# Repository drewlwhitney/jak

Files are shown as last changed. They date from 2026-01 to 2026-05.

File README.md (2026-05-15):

# Just Another Keyboard
It's Just Another Keyboard that amalgamates the [Corne](github.com/foostan/crkbd), [Ferris Sweep](https://github.com/davidphilipbarr/Sweep), and [Fifi](https://github.com/raychengy/fifi_split_keeb).

Wired | Wireless
-|-
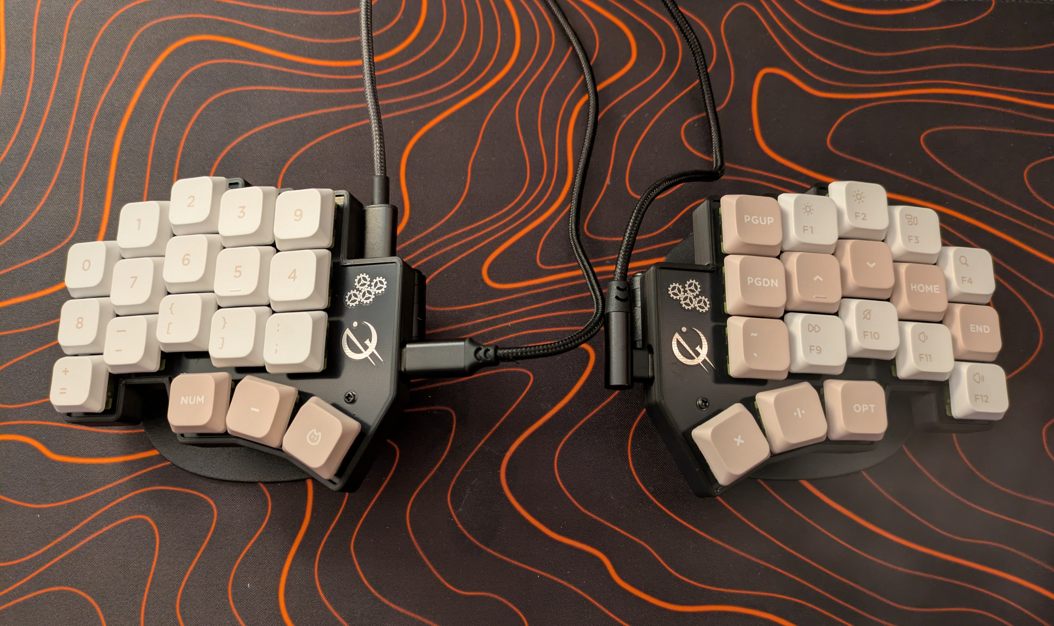
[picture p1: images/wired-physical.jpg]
wired_physical
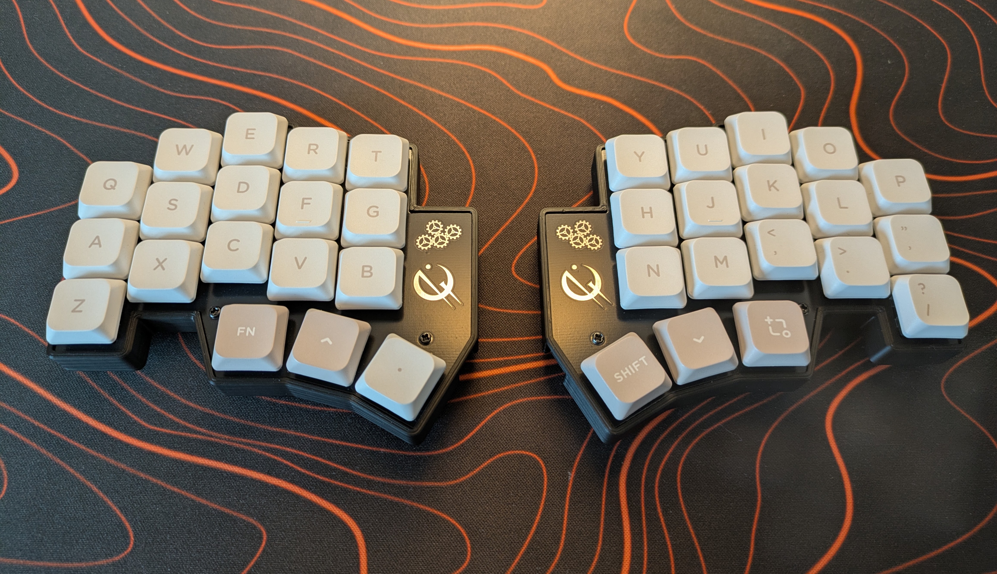
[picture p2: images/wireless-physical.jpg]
wireless_physical
 | 
<sub>Fully assembled wired version with keycaps from Nuphy</sub> | <sub>Fully assembled wireless version

## Notable Features
- Designed for [Gateron KS-33 Low Profile Switches](https://www.gateron.co/products/gateron-low-profile-mechanical-switch-set) with hotswap sockets

- Uses the [Seeed Studio XIAO microcontroller](https://www.seeedstudio.com/XIAO-RP2040-v1-0-p-5026.html) with either the [RP2040](https://www.seeedstudio.com/XIAO-RP2040-v1-0-p-5026.html) variant (for wired builds) or the [XIAO-BLE](https://www.seeedstudio.com/Seeed-XIAO-BLE-nRF52840-p-5201.html) variant (for wireless builds)

- 2-pin JST connector for the battery in wireless builds

- USB-C full duplex USART communication for wired builds. None of that [TRRS nonesense](https://gabevenberg.com/posts/stop-using-trrs/)!

- [Switch plates](./switch-plate/) you can order with the PCB

- [3D printable cases](./case/) that exactly fit the boards with a battery or USB-C connectors

## Build Guide
Refer to the [Build Guide](./docs/build_guide.md).

## Firmware Guide
### ZMK
You can use ZMK with *either* the wired or wireless version of the keyboard.

- Follow the [usual setup steps for ZMK](https://zmk.dev/docs/user-setup).

- Add the `zmk-keyboards-jak` module by following the instructions on the [module's GitHub](https://github.com/drewlwhitney/zmk-keyboards-jak).

- For wired builds, follow the extra steps on the [module's GitHub](https://github.com/drewlwhitney/zmk-keyboards-jak).

- Build and flash the firmware.

### QMK
You can use QMK with the **wired version only**.

- Follow the [usual setup steps for QMK](https://docs.qmk.fm/newbs).

- Clone the [keyboard description repo](https://github.com/drewlwhitney/qmk-keyboards-jak) into your `qmk_firmware/keyboards` folder and rename it to `"jak"`.[^1]

- Follow the build instructions from the [keyboard description repo](https://github.com/drewlwhitney/qmk-keyboards-jak).

[^1]: If there is a better way to do this, please open an issue to let me know!

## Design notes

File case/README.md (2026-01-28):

# Case
Left and right case files which can be 3D printed. There are two versions: one for a wired build and one for a wireless build.

## Wireless
Use the [wireless left](./left-wireless.step) and [wireless right](./right-wireless.step) files. This version omits holes for the split USB-C connectors and adds holes for the power switches. It is tall enough to fit a battery on the underside of the PCB.

This case uses 10mm M2 screws.

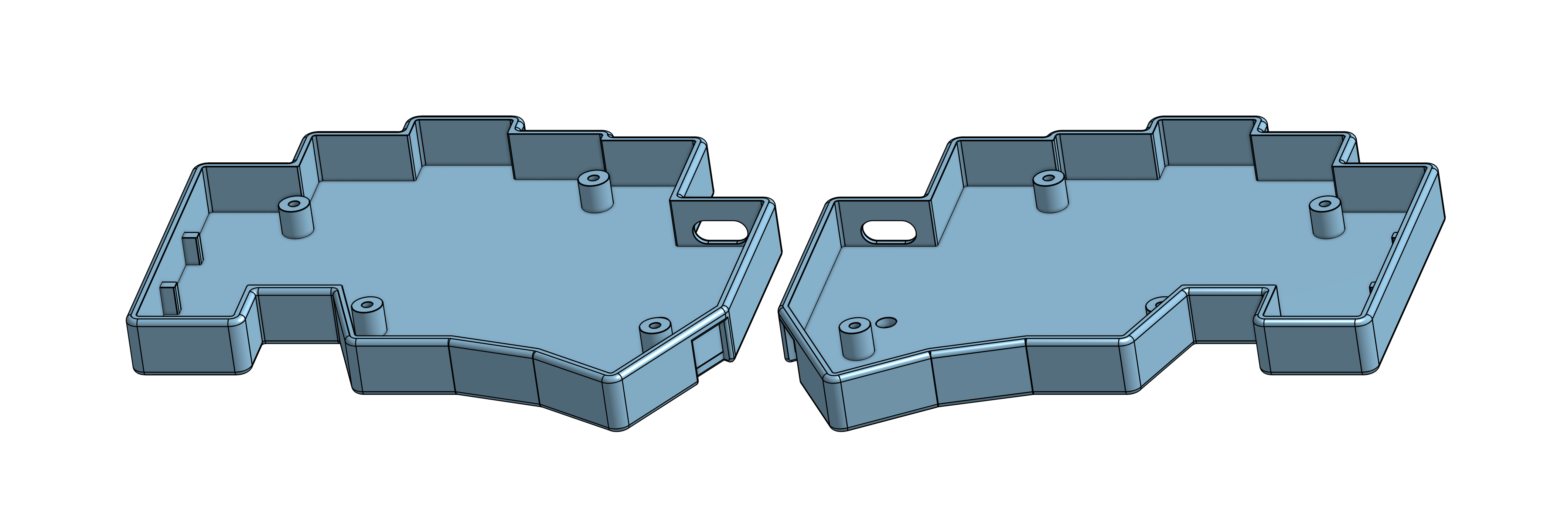
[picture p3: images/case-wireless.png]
case_wireless_onshape


## Wired
Use the [wired left](./left-wired.step) and [wired right](./right-wired.step) files. This version omits holes for the power switch and adds holes for the split USB-C connectors. It is tall enough to exactly fit the switch plate and PCB (with components) with nothing underneath.

This case uses 8mm M2 screws.

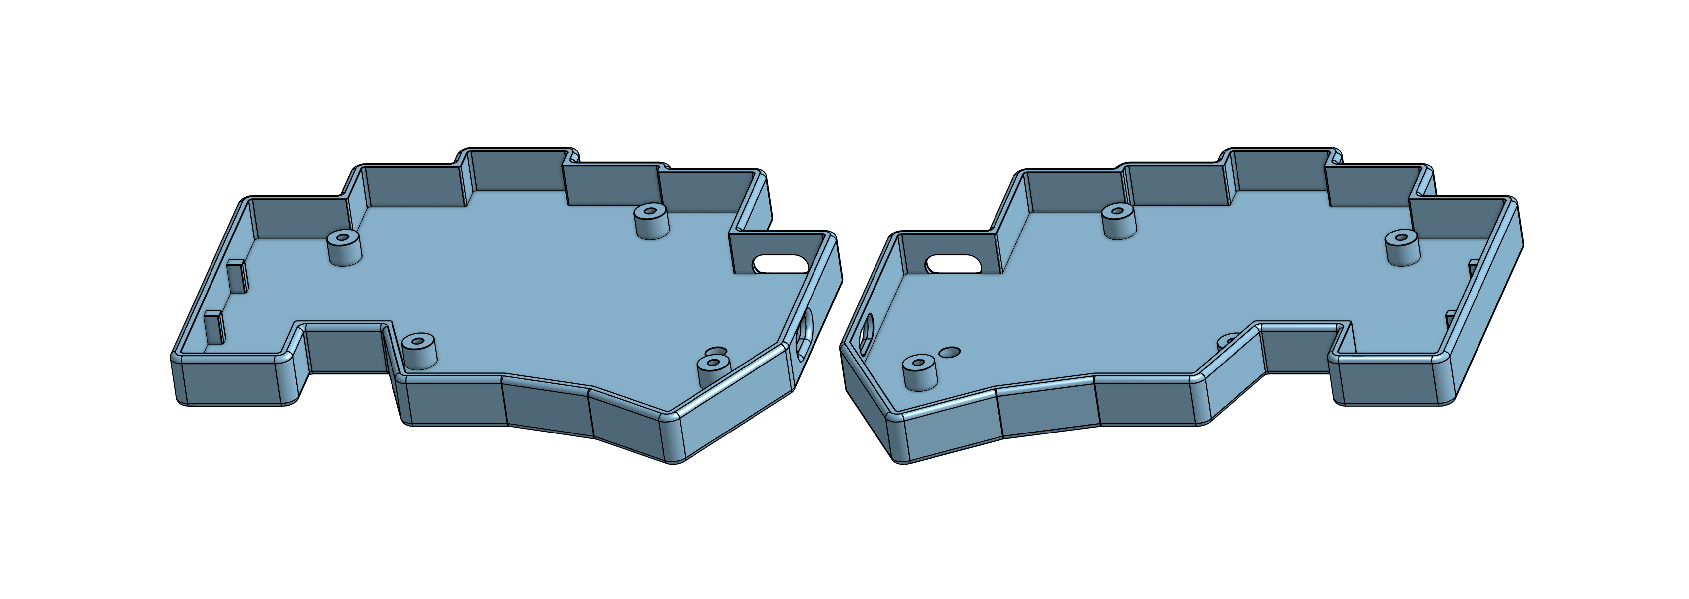
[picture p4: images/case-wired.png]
case_wired_onshape


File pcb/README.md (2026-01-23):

## PCB
The PCB is non-reversible and is designed for Gateron KS-33 Low Profile Switches with hotswap sockets.

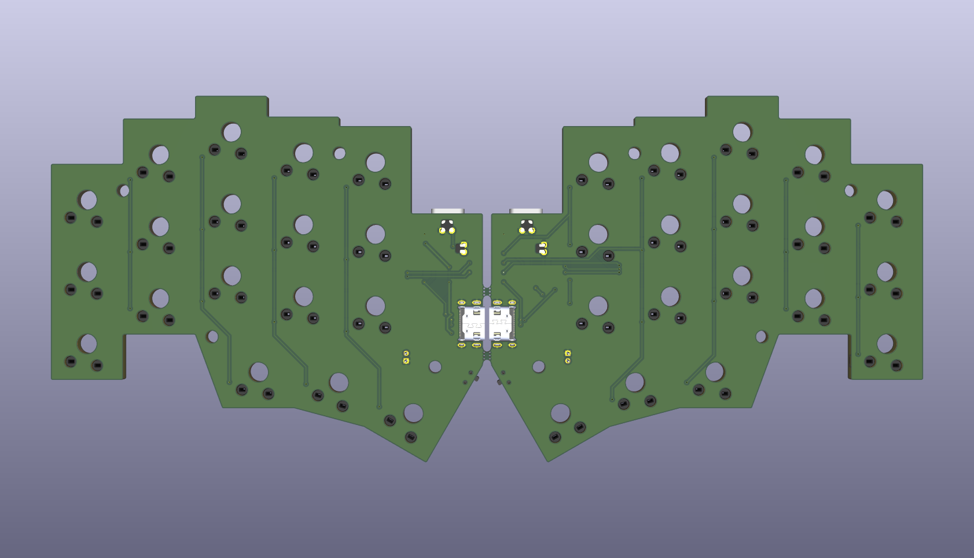
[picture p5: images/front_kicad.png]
front

<sub>Front</sub>

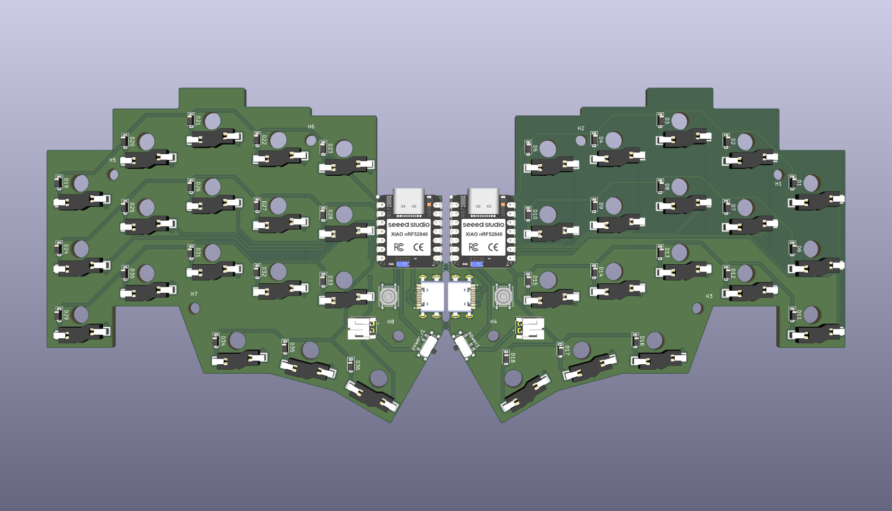
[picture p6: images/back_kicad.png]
back

<sub>Back</sub>

## Ordering
This was written on January 7, 2026 for [JLCPCB](https://jlcpcb.com/).

Upload the [PCB Gerber Files (.zip)](./gerbers/) to [JLCPCB](https://cart.jlcpcb.com/quote), then leave everything as-is except for:

| Option | Value |
| -- | -- |
| Different Design | 2 |
| PCB Color | Your choice |

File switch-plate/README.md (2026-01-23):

# Switch Plate
There are two versions of the switch plate:
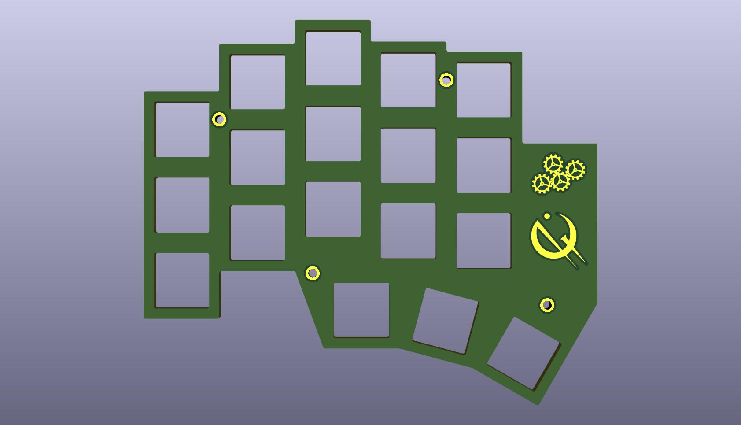
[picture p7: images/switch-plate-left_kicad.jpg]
switch-plate-left
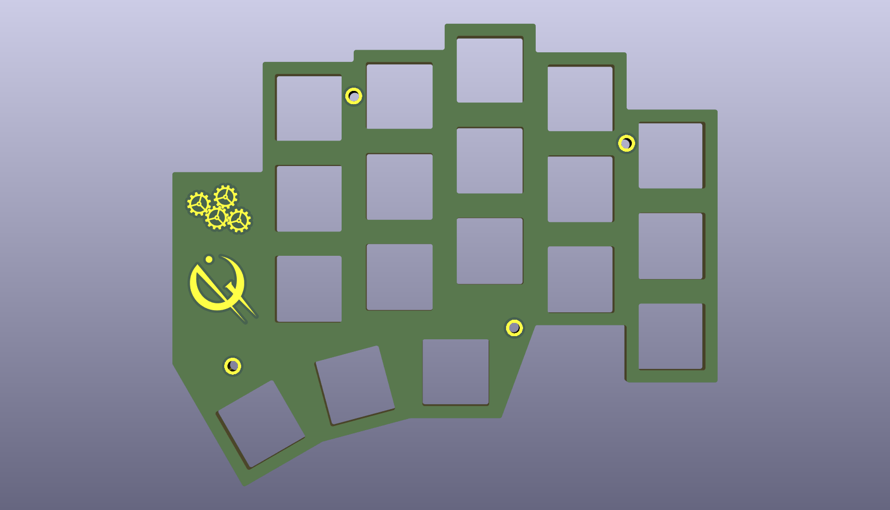
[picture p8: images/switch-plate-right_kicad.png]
switch-plate-right
- [`switch-plate-left`](./switch-plate-left/) and [`switch-plate-right`](./switch-plate-right/) - Non-reversible switch plates that have decorative markings made out of exposed metal. The metal markings look very cool, but they can only be on the top side of the plate because the exposed metal could short the battery terminals if they were on the bottom. You need to order both the left and right plates.  

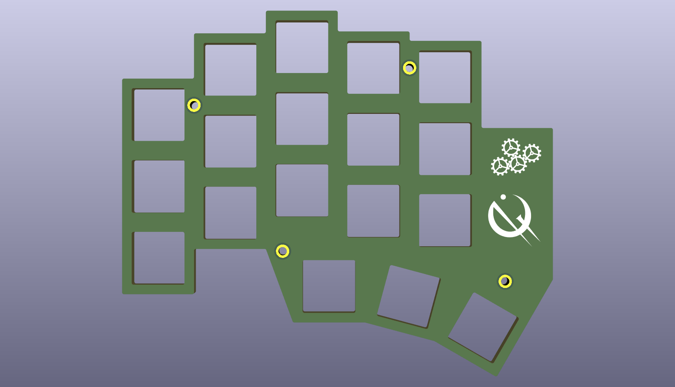
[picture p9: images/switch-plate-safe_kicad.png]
switch-plate-safe
- [`switch-plate-safe`](./switch-plate-safe/) - A reversible switch plate that moves the decorative markings to the silkscreen. You only need to order one set (i.e. get at least two plates and then flip one over). 

Both plates are designed for MX-style switches (including the Gateron KS-33 Low Profile Switches).

## Ordering
This was written on January 23, 2026 for [JLCPCB](https://jlcpcb.com/).

If using the left and right switch plates, you'll need two sets of Gerber files: one for the [left](./switch-plate-left/gerbers/) and one for the [right](./switch-plate-right/gerbers/). If using the reversible switch plate, you only need [this one](./switch-plate-safe/gerbers/).

Upload the Gerber files (.zip) to [JLCPCB](https://cart.jlcpcb.com/quote), then leave everything as-is except for:

| Option | Value |
| -- | -- |
| PCB Color | Your choice |

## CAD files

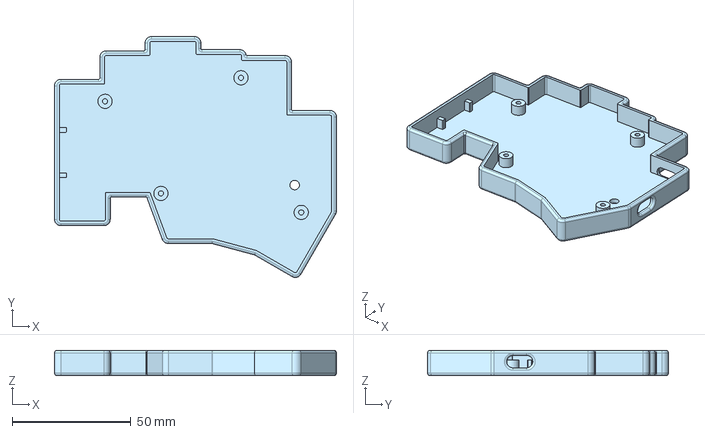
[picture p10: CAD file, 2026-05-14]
case/left-wired.step
118.6 x 101.3 x 10.6 mm

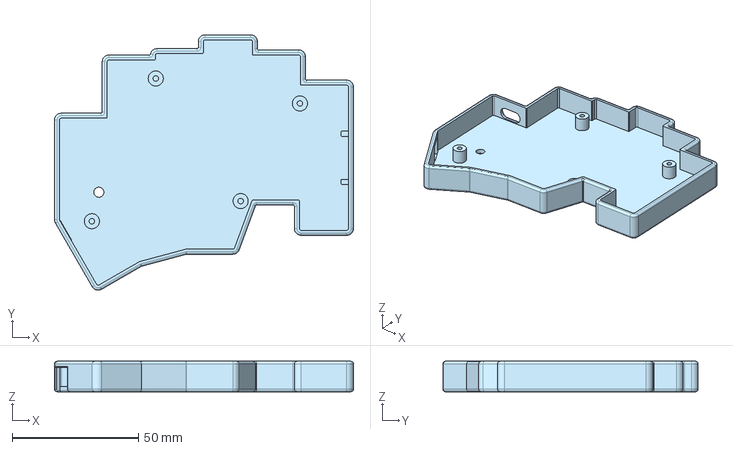
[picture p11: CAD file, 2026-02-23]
case/right-wireless.step
118.6 x 101.3 x 12.1 mm

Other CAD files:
case/right-wired.step
case/left-wireless.step

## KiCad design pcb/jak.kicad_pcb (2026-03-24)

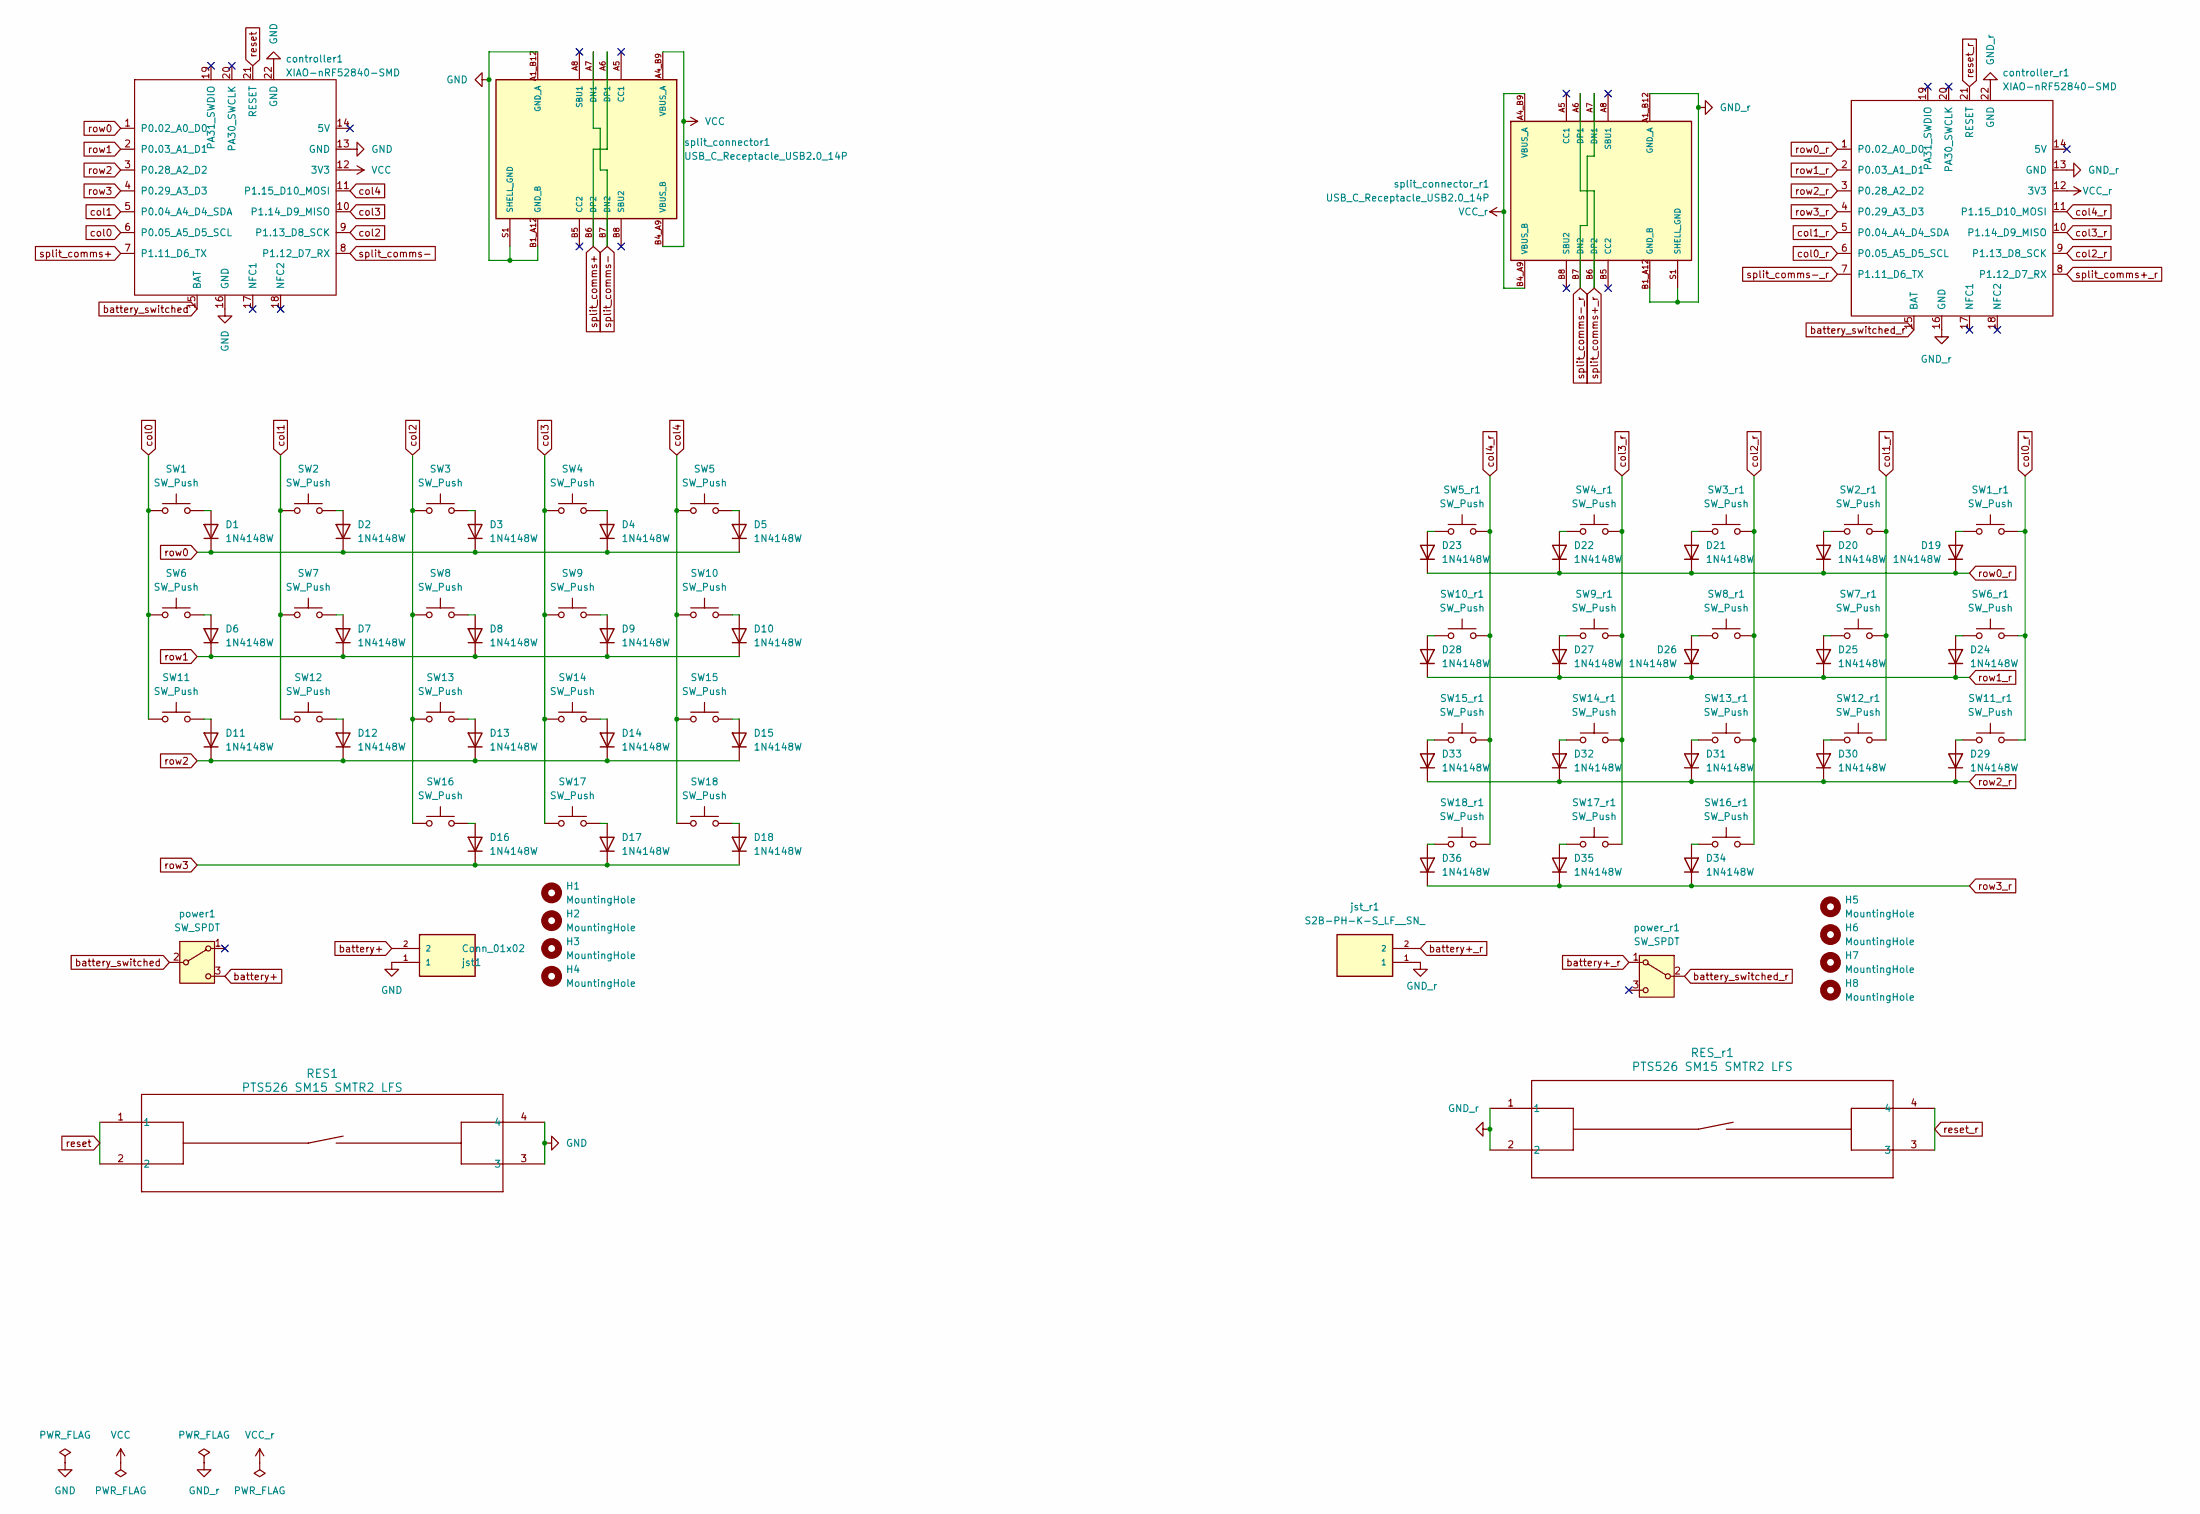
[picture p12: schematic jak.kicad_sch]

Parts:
D1, D2, D3, D4, D5, D6, D7, D8, D9, D10, D11, D12, D13, D14, D15, D16, D17, D18, D19, D20, D21, D22, D23, D24, D25, D26, D27, D28, D29, D30, D31, D32, D33, D34, D35, D36: 1N4148W; D_SOD-123
H1, H2, H3, H4, H5, H6, H7, H8: MountingHole; MountingHole_3.2mm_M3
RES1: PTS526 SM15 SMTR2 LFS; SON4_PTS526 SM15 SMTR2 LFS_CNK
RES_r1: PTS526 SM15 SMTR2 LFS; SON4_PTS526 SM15 SMTR2 LFS_CNK
SW1, SW1_r1, SW2, SW2_r1, SW3, SW3_r1, SW4, SW4_r1, SW5, SW5_r1, SW6, SW6_r1, SW7, SW7_r1, SW8, SW8_r1, SW9, SW9_r1, SW10, SW10_r1, SW11, SW11_r1, SW12, SW12_r1, SW13, SW13_r1, SW14, SW14_r1, SW15, SW15_r1, SW16, SW16_r1, SW17, SW17_r1, SW18, SW18_r1: SW_Push; Gateron-KS33-Hotswap-1U
controller1: XIAO-nRF52840-SMD; XIAO-nRF52840-SMD-underside
controller_r1: XIAO-nRF52840-SMD; XIAO-nRF52840-SMD-underside
jst1: Conn_01x02; JST_S2B-PH-K-S_LF__SN_
jst_r1: S2B-PH-K-S_LF__SN_; JST_S2B-PH-K-S_LF__SN_
power1: SW_SPDT; SW_SPDT_PCM12
power_r1: SW_SPDT; SW_SPDT_PCM12
split_connector1: USB_C_Receptacle_USB2.0_14P; GCT_USB4505-03-0-A_REVA; PARTREV A
split_connector_r1: USB_C_Receptacle_USB2.0_14P; GCT_USB4505-03-0-A_REVA; PARTREV A

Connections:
GND: RES1.3, RES1.4, controller1.13 (GND), controller1.16 (GND), controller1.22 (GND), jst1.1, split_connector1.A1_B12 (GND_A), split_connector1.B1_A12 (GND_B), split_connector1.S1 (SHELL_GND), split_connector1.S2 (SHELL_GND), split_connector1.S3 (SHELL_GND), split_connector1.S4 (SHELL_GND)
GND_r: RES_r1.1, RES_r1.2, controller_r1.13 (GND), controller_r1.16 (GND), controller_r1.22 (GND), jst_r1.1, split_connector_r1.A1_B12 (GND_A), split_connector_r1.B1_A12 (GND_B), split_connector_r1.S1 (SHELL_GND), split_connector_r1.S2 (SHELL_GND), split_connector_r1.S3 (SHELL_GND), split_connector_r1.S4 (SHELL_GND)
unnamed: D1.2 (A), SW1.2
unnamed: D2.2 (A), SW2.2
unnamed: D3.2 (A), SW3.2
unnamed: D4.2 (A), SW4.2
unnamed: D5.2 (A), SW5.2
unnamed: D6.2 (A), SW6.2
unnamed: D7.2 (A), SW7.2
unnamed: D8.2 (A), SW8.2
unnamed: D9.2 (A), SW9.2
unnamed: D10.2 (A), SW10.2
unnamed: D11.2 (A), SW11.2
unnamed: D12.2 (A), SW12.2
unnamed: D13.2 (A), SW13.2
unnamed: D14.2 (A), SW14.2
unnamed: D15.2 (A), SW15.2
unnamed: D16.2 (A), SW16.2
unnamed: D17.2 (A), SW17.2
unnamed: D18.2 (A), SW18.2
unnamed: D19.2 (A), SW1_r1.2
unnamed: D20.2 (A), SW2_r1.2
unnamed: D21.2 (A), SW3_r1.2
unnamed: D22.2 (A), SW4_r1.2
unnamed: D23.2 (A), SW5_r1.2
unnamed: D24.2 (A), SW6_r1.2
unnamed: D25.2 (A), SW7_r1.2
unnamed: D26.2 (A), SW8_r1.2
unnamed: D27.2 (A), SW9_r1.2
unnamed: D28.2 (A), SW10_r1.2
unnamed: D29.2 (A), SW11_r1.2
unnamed: D30.2 (A), SW12_r1.2
unnamed: D31.2 (A), SW13_r1.2
unnamed: D32.2 (A), SW14_r1.2
unnamed: D33.2 (A), SW15_r1.2
unnamed: D34.2 (A), SW16_r1.2
unnamed: D35.2 (A), SW17_r1.2
unnamed: D36.2 (A), SW18_r1.2
VCC: controller1.12 (3V3), split_connector1.A4_B9 (VBUS_A), split_connector1.B4_A9 (VBUS_B)
VCC_r: controller_r1.12 (3V3), split_connector_r1.A4_B9 (VBUS_A), split_connector_r1.B4_A9 (VBUS_B)
battery+: jst1.2, power1.3 (C)
battery+_r: jst_r1.2, power_r1.1 (A)
battery_switched: controller1.15 (BAT), power1.2 (B)
battery_switched_r: controller_r1.15 (BAT), power_r1.2 (B)
col0: SW1.1, SW6.1, SW11.1, controller1.6 (P0.05_A5_D5_SCL)
col0_r: SW1_r1.1, SW6_r1.1, SW11_r1.1, controller_r1.6 (P0.05_A5_D5_SCL)
col1: SW2.1, SW7.1, SW12.1, controller1.5 (P0.04_A4_D4_SDA)
col1_r: SW2_r1.1, SW7_r1.1, SW12_r1.1, controller_r1.5 (P0.04_A4_D4_SDA)
col2: SW3.1, SW8.1, SW13.1, SW16.1, controller1.9 (P1.13_D8_SCK)
col2_r: SW3_r1.1, SW8_r1.1, SW13_r1.1, SW16_r1.1, controller_r1.9 (P1.13_D8_SCK)
col3: SW4.1, SW9.1, SW14.1, SW17.1, controller1.10 (P1.14_D9_MISO)
col3_r: SW4_r1.1, SW9_r1.1, SW14_r1.1, SW17_r1.1, controller_r1.10 (P1.14_D9_MISO)
col4: SW5.1, SW10.1, SW15.1, SW18.1, controller1.11 (P1.15_D10_MOSI)
col4_r: SW5_r1.1, SW10_r1.1, SW15_r1.1, SW18_r1.1, controller_r1.11 (P1.15_D10_MOSI)
reset: RES1.1, RES1.2, controller1.21 (RESET)
reset_r: RES_r1.3, RES_r1.4, controller_r1.21 (RESET)
row0: D1.1 (K), D2.1 (K), D3.1 (K), D4.1 (K), D5.1 (K), controller1.1 (P0.02_A0_D0)
row0_r: D19.1 (K), D20.1 (K), D21.1 (K), D22.1 (K), D23.1 (K), controller_r1.1 (P0.02_A0_D0)
row1: D6.1 (K), D7.1 (K), D8.1 (K), D9.1 (K), D10.1 (K), controller1.2 (P0.03_A1_D1)
row1_r: D24.1 (K), D25.1 (K), D26.1 (K), D27.1 (K), D28.1 (K), controller_r1.2 (P0.03_A1_D1)
row2: D11.1 (K), D12.1 (K), D13.1 (K), D14.1 (K), D15.1 (K), controller1.3 (P0.28_A2_D2)
row2_r: D29.1 (K), D30.1 (K), D31.1 (K), D32.1 (K), D33.1 (K), controller_r1.3 (P0.28_A2_D2)
row3: D16.1 (K), D17.1 (K), D18.1 (K), controller1.4 (P0.29_A3_D3)
row3_r: D34.1 (K), D35.1 (K), D36.1 (K), controller_r1.4 (P0.29_A3_D3)
split_comms+: controller1.7 (P1.11_D6_TX), split_connector1.A6 (DP1), split_connector1.B6 (DP2)
split_comms+_r: controller_r1.8 (P1.12_D7_RX), split_connector_r1.A6 (DP1), split_connector_r1.B6 (DP2)
split_comms-: controller1.8 (P1.12_D7_RX), split_connector1.A7 (DN1), split_connector1.B7 (DN2)
split_comms-_r: controller_r1.7 (P1.11_D6_TX), split_connector_r1.A7 (DN1), split_connector_r1.B7 (DN2)

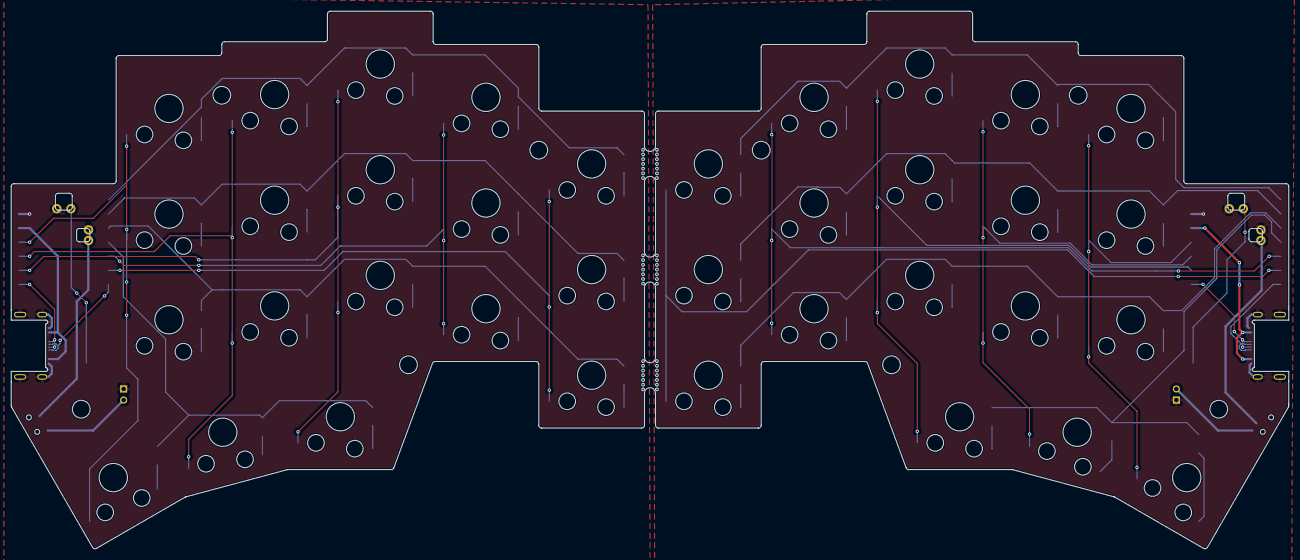
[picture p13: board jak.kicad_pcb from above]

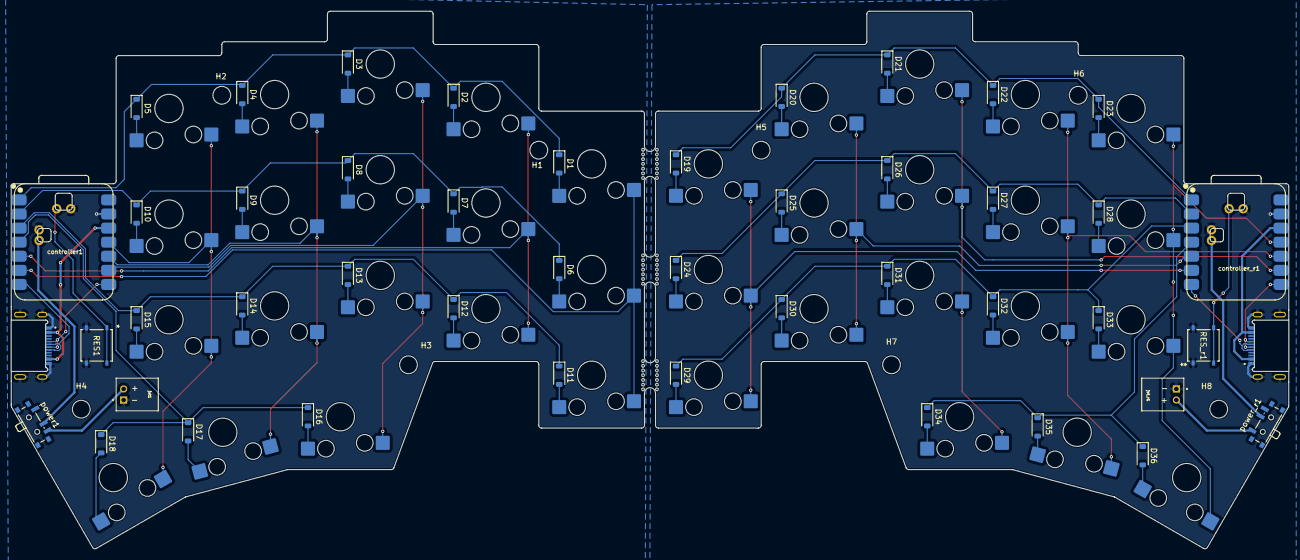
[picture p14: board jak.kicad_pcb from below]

Board: 2 copper layers, 230.3 x 96.9 mm, 90 parts (82 on the bottom side), 68 nets.

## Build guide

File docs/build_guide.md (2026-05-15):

# Build Guide
This is not a full build guide. I've provided a [bill of materials](#bill-of-materials) and some links to general keyboard building guides. This is not a simple build, so some soldering experience (especially surface-mount soldering) is required. You will need to reference the [PCB](../pcb/) to know which components go where.

Building a keyboard like this consists of purchasing components, soldering the components, installing switches and keycaps, and possibly assembling the case. For general walk-throughs, refer to the [wireless Corne guide](https://docs.typeractive.xyz/build-guides/corne-wireless) (which is not a one-to-one guide for this keyboard, but has some useful tutorials).

## Bill of Materials
The provided links are for components that I know work, but feel free to use any other sellers/compatible components.

### General
- 1x [PCB Set](../pcb/)

- 2x [Seeed Studio XIAO RP2040 Controllers](https://www.seeedstudio.com/XIAO-RP2040-v1-0-p-5026.html)<sup>1</sup>

- x36 [1N4148W Diodes](https://typeractive.xyz/products/smd-diodes)

- x36 [Gateron Low Profile Hotswap Sockets](https://www.gateron.co/products/gateron-low-profile-mechanical-switch-set)

- x36 [Gateron KS-33 Low Profile Switches](https://www.gateron.co/products/gateron-low-profile-mechanical-switch-set)

- x36 Low Profile Keycaps (such as [these](https://nuphy.com/collections/keycaps/products/coast-dawn-nsa?_pos=16&_fid=607ff251a&_ss=c))

- 2x [PTS526SM15SMTR2 LFS Reset Buttons](https://www.digikey.com/en/products/detail/c-k/PTS526SM15SMTR2-LFS/10056625)

- [Switch Plates](../switch-plate/)

- (optional) 1x [3D Printable Case](../case/) (left and right)
    - If using the case, you'll also want 8x 8mm M2 screws.

<br>

<sup>1</sup> For wireless builds, use the `XIAO BLE` instead

### Wireless-Specific
Buy these components in addition to those in the [`General`](#general) section for wireless builds:

- 2x [XIAO BLE Controllers](https://www.seeedstudio.com/Seeed-XIAO-BLE-nRF52840-p-5201.html) (*which replace the XIAO RP2040 Controllers*)

- 2x [JST Connectors](https://typeractive.xyz/products/battery-jack) for batteries

- 2x Lithium Batteries
    - The [301230 110mAh Battery](https://typeractive.xyz/products/lithium-battery-110mah) is good for lighter boards if you don't need the battery life to last longer than a week.
    - Otherwise, you can use a larger battery, such as [this one](https://typeractive.xyz/products/lithium-battery-750mah).

- 2x [Power Switches](https://typeractive.xyz/products/power-switch)

### Wired-Specific
Buy these components in addition to those in the [`General`](#general) section for wired builds:

- 2x [Mid-Mount USB-C Connectors](https://www.digikey.com/en/products/detail/gct/USB4505-03-0-A/15283201) to connect the two halves

## Notes
- For wireless builds:
    - Ensure the polarity of your batteries matches the markings on the PCB. [These batteries](https://typeractive.xyz/products/lithium-battery-110mah) have the correct polarity, but there is no consistent standard for JST connectors.

- When soldering the PCB, all diodes should have the cathode on the top pad.

- Before mounting the switches, make sure you solder the pads on the back of the microcontroller (there are holes in the PCB and wall-lining copper for solder to adhere to). These are for the reset button.
    - For wireless builds, there are also extra pads for the battery terminals.

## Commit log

2026-01-07 Replaced the through-hole surface USB-C connector with a flush one
    [USB4505-03-0-A_REVA.step, jak.kicad_pcb, jak.kicad_sch]
2026-01-07 Added a 3D printable case
    [case-left.step, case-right.step]
2026-01-08 Fixed the submodule issus for the symbol and footprint libraries
    [jak.kicad_pcb, switch-plate.kicad_pcb]
2026-01-08 Forgot files
    [USB4505-03-0-A_REVA.step]
2026-01-08 Updated README and added READMEs for the PCB, switch plate, and case. Added a build guide with bill of materials
2026-01-08 Fix typo in README for case files description
2026-01-20 In the process of transitioning the board to use the SEEED XIAO instead of a pro micro
    [PCM12SMTR.step, PTS526SM15SMTR2LFS.stp, S2B-PH-K-S_LF__SN_.step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]
2026-01-23 Made some final changes to the pcb and split the switch plate into two versions to allow metal decorations
    [USB4505-03-0-A_REVA.step, jak.kicad_pcb, jak.kicad_sch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]
2026-01-23 Fixed switch plate README
2026-01-23 Fixed PCB README
2026-01-26 Making sure we're up to date
    [jak.kicad_pcb, jak.kicad_sch]
2026-01-26 Clarify diode orientation for soldering PCB
    Added note about diode orientation during soldering.
2026-01-27 Modified the pcb to have stronger mousebites
    [jak.kicad_pcb]
2026-01-28 Updated the case and split it into wired and wireless variants
    [case-left.step, case-right.step, left-wired.step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]
2026-01-28 Updated the build guide and case README to specify the M2 screw length
2026-02-23 Updated the cases to better brace the outer PCB edges
    [left-wired.step, left-wireless.step, right-wired.step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]
2026-02-23 Fixed the footprint for the reset switch, as it was wrong on the website I got it from
    [jak.kicad_pcb]
2026-02-28 Fixed the power switch pins being swapped and updated the gerber files
    [jak.kicad_pcb, jak.kicad_sch]
2026-03-24 Revert "Fixed the power switch pins being swapped and updated the gerber files"
    This reverts commit 317bf88c69a0fc961124c453349158f4046b94f1.
    [jak.kicad_pcb, jak.kicad_sch]
2026-03-24 Reverted the power switch fix, I actually like this mode
2026-03-24 Updated the gerbers
2026-03-24 Removed some backups
    [jak.kicad_pcb]
2026-03-24 Updated stuff after building the wireless version
2026-03-24 Updated the case pictures
2026-05-14 Fixed the wired case and updates the qmk stuff
    [left-wired.step, right-wired.step]
2026-05-15 Updated the docs for the wired version!
2026-07-03 Deleted some libraries that I was not supposed to have on GitHub (just in case)
    [PCM12SMTR.step, PTS526SM15SMTR2LFS.stp, S2B-PH-K-S_LF__SN_.step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]
